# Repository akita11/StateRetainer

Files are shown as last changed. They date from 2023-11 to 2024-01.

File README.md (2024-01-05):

# StateRetainer

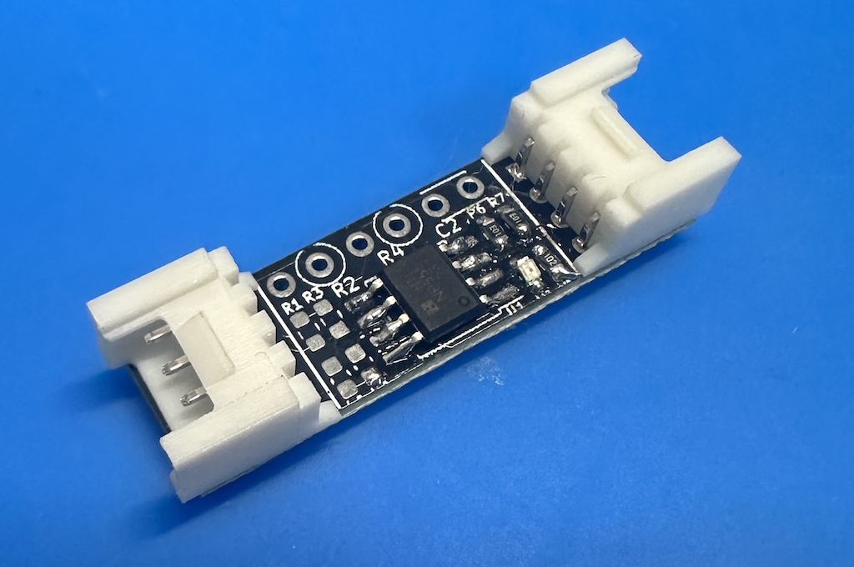
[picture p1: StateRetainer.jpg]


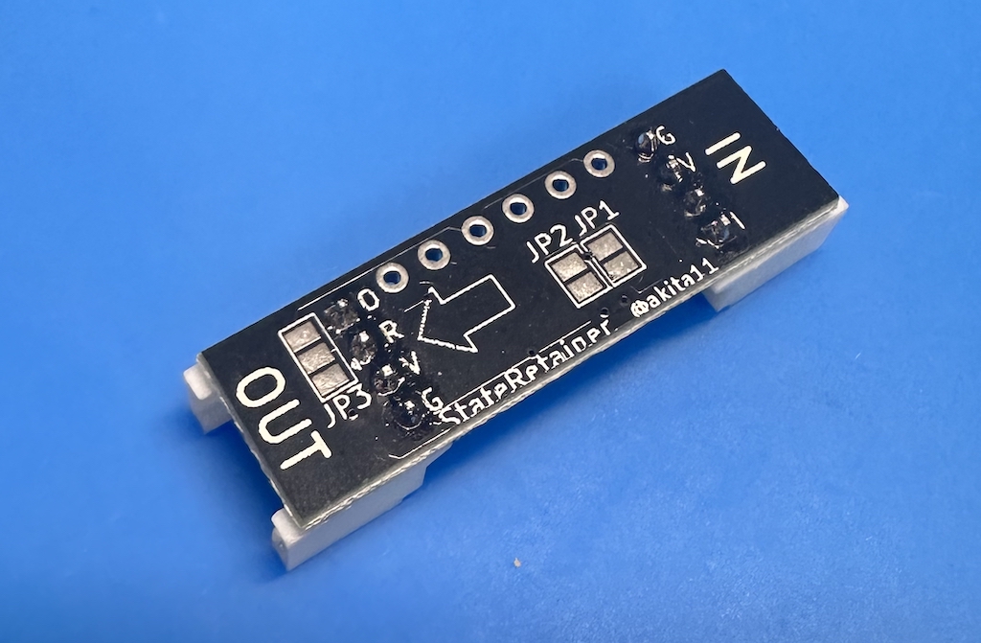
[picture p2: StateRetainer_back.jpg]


Grove端子のデジタル信号の変化を、マイコン等で扱いやすいように「保持」するものです。スイッチを短い時間押す、などの単発信号をとらえ、一定時間、またはリセットを書けるまで、出力にその値を保持します。

内部的は、いわゆる"555"をそのまま使っています。（参考：[555の動作](https://www.marutsu.co.jp/contents/shop/marutsu/mame/166.html)）

## ピン配置

- Grove（In側）: IN/x/VDD/GND ※INは入力（プルアップ）
- Grove（Out側）: OUT/RST/VDD/GND ※OUTは出力、RSTは入力（プルダウン）

OUT=1の時には、LEDが点灯し、出力の状態を確認できます。

※内部の回路(555)はGrove端子から供給される電源電圧で動作するため、RST入力を"1"とするには、電源電圧の2/3以上の電圧が必要です。またOUT出力の"1"の電圧も電源電圧となります。M5StackシリーズではVDDは5VですがIO電圧は3.3Vのため、RSTはぎりぎり"1"に足りません（個体差で"1"と判別される場合もあります）。またOUTの"1"は5Vのため、IOピンの入力電圧の範囲を超えます。そのため、確実な動作のためには、Grove端子の電源電圧として3.3Vを供給してください（[こちら](https://www.switch-science.com/products/9461)を使うとGroveケーブルの中継としてはさむことで3.3Vを生成して供給できます）

## 動作

目的にあわせて、以下の3通りの動作状態を設定できます。

### 保持動作（デフォルト状態）

INの状態変化を出力に保持します。いわゆるRSフリップフロップとしての動作です。なおINは内部でプルアップ、RSTはプルダウンされているので、IN、RSTの開放時には、それぞれ"1"、"0"と同等です（待機状態）。

- INが1→0になると、OUT=1となり、その状態を保持。
- その状態で、RSTを0→1とすると、OUT=0に復帰。

【構成】: C1/C2、R1/R3、R2/R4に部品を取り付けなず、JP1/JP2を開放（初期状態）

### 単発パルス発生動作

INが1→0になると、指定時間（T=1.1*CR[s]）間のみ、OUT=1となり、その後、OUT=1に復帰します。

- 【構成】: R7を除去し、C1/C2にコンデンサC、R1/R3に抵抗Rを接続し、R2/R4は抵抗を取り付けず、JP1を短絡、JP2を開放

### 発振動作

入力に関係なく、f=1.44 / (Ra + 2*Rb)C [Hz]で発振します。

- 【構成】: R6, R7を除去し、R1/R3にRa、R2/R4にRb、C1/C2にCを接続し、JP2を短絡、JP1を開放

## 出力の極性の切り替え

出力OUTはJP3によって、正論理（デフォルト、OFF時=0、ON時=1）・負論理（オープンコレクタ、OFF時=開放、ON時=0）を切り替えできます。負論理の場合は保持動作時にはR1/R3にプルアップ抵抗を取り付け可能。上記のOUTの値の表記は正論理時の値の表記です。

## Author

Junichi Akita (akita@ifdl.jp, @akita11)

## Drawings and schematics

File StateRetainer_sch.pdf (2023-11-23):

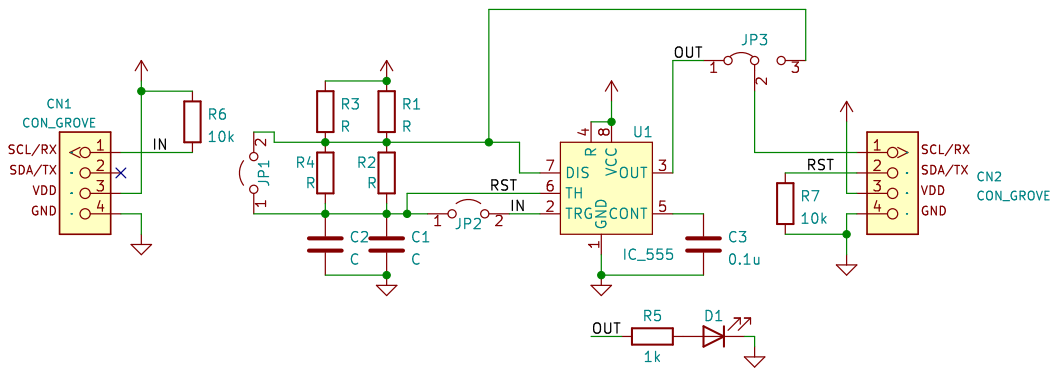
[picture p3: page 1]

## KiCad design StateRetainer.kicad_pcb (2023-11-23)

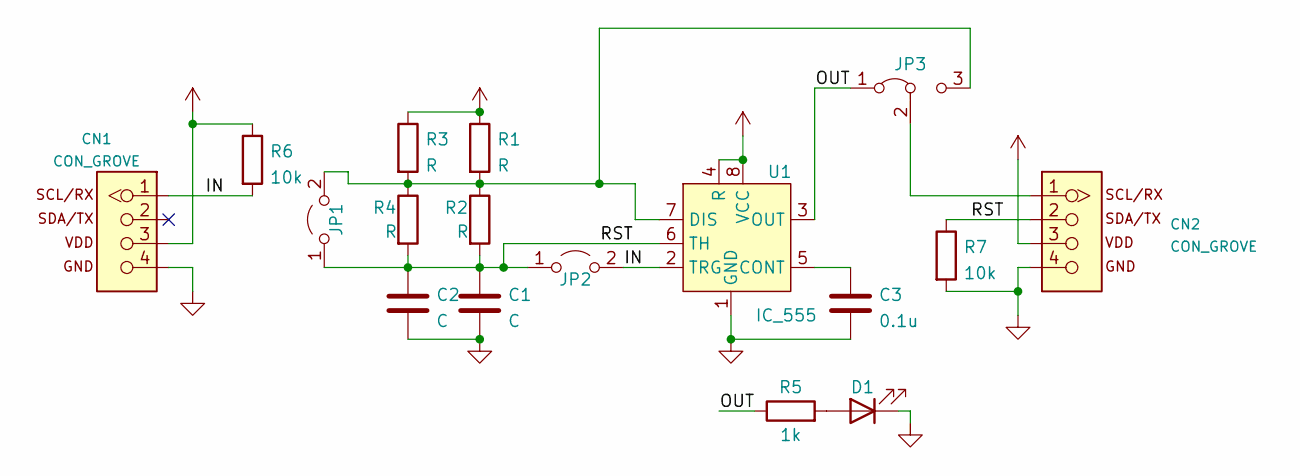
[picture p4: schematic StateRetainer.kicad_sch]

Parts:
C1: C; C_0603_1608Metric
C2: C; C_Disc_D3.0mm_W2.0mm_P2.50mm
C3: 0.1u; C_0603_1608Metric
CN1, CN2: CON_GROVE; CON_GROVE_H
D1: LED; C_0603_1608Metric
JP1, JP2: Jumper_2_Open; SolderJumper-2_P1.3mm_Open_Pad1.0x1.5mm
JP3: Jumper_3_Bridged12; SolderJumper-3_P1.3mm_Bridged2Bar12_Pad1.0x1.5mm
R1, R2: R; R_0603_1608Metric
R3, R4: R; R_Axial_DIN0207_L6.3mm_D2.5mm_P2.54mm_Vertical
R5: 1k; R_0603_1608Metric
R6, R7: 10k; R_0603_1608Metric
U1: IC_555; SOIC-8_5.23x5.23mm_P1.27mm

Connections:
/IN: CN1.1, JP2.2 (B), R6.2, U1.2 (TRG)
/OUT: JP3.1 (A), R5.1, U1.3 (OUT)
/RST: C1.1, C2.1, CN2.2, JP1.1 (A), JP2.1 (A), R2.2, R4.2, R7.1, U1.6 (TH)
GND: C1.2, C2.2, C3.2, CN1.4, CN2.4, D1.1 (K), R7.2, U1.1 (GND)
unnamed: C3.1, U1.5 (CONT)
unnamed: CN2.1, JP3.2 (C)
unnamed: D1.2 (A), R5.2
unnamed: JP1.2 (B), JP3.3 (B), R1.2, R2.1, R3.2, R4.1, U1.7 (DIS)
VCC: CN1.3, CN2.3, R1.1, R3.1, R6.1, U1.4 (R), U1.8 (VCC)

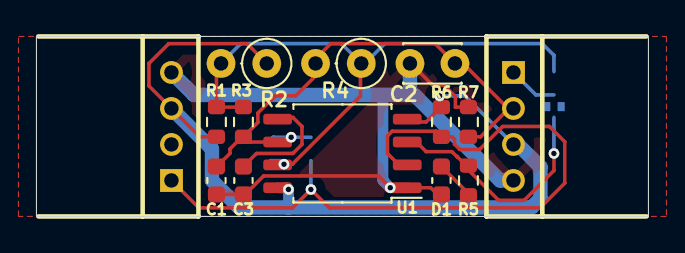
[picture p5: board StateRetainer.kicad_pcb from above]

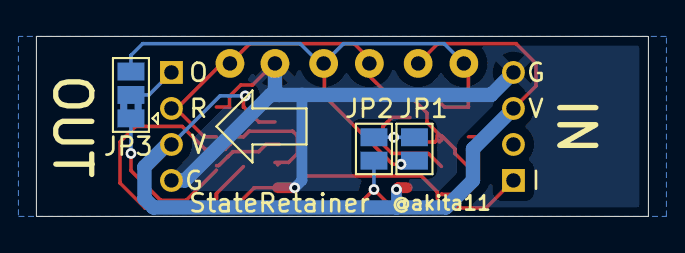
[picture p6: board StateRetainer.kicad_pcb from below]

Board: 2 copper layers, 34.0 x 10.0 mm, 17 parts (3 on the bottom side), 9 nets.
